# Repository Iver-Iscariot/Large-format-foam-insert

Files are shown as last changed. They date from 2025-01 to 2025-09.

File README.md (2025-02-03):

Making a custom trunk to carry my large format camera, with a fitted foam padding on the inside

CAD file of my camera 

Its a cambo monorail-type large format camera



I have modelled all the components, and laid them out in a desirable, ergonomic layout (Things can be accessed in the order of when you assemble them (this was a issue with the case i bought it in)).
I then drew some simple box-envelopes around them, such that they have some tolerance. These envelope-boxes are also in increments of 5mm height wise, as this is limited by the foam i will be using.

On that, it was hard to find a supplyer of (laser cuttable) foam in norway, but i ended up with this from rufo
https://www.rufo.no/products/50-mm-plastazo3
Its a laminate of 5mm foam layers that can be pulled apart.

Originally, I wanted to fit this in a peli-case with a suitcase-style pullbar and wheels, but there was no way this would fit. Especially since i wanted to store the camera semi-assembled in the case (it typically takes ~20min to take ONE picture with this camera, so every time-save is worth it)
I will therefore simply lasercut a dovetail-plywood box for it, and install some hardware.
To make it suitcase-style, i will use a "sekketralle" from clas ohlson
https://www.clasohlson.com/no/Sammenleggbar-tralle/p/40-8867
I will lasercut some plywood pieces matching the pattern on the bottom, so that it can be slotted onto it (and attached to the handle bar with some sort of straps) I need to use the sekketralle for other stuff, and it is practical to be able to remove the trunk and carry as a backpack with some sort of straps, if you're shooting in rugged terrain

----------------------------------------------------------------------------------------------------------------------------------------------------------------------------------------------------------
EDIT: Making the inside purely out of foam would be VERY expensive. I therefore pivoted to making inside walls, and put padding on them 


I use boxes.py to generate the lasercut-files using this text carefully calculated from my cad file
https://boxes.hackerspace-bamberg.de/TrayLayout?

```
Height: 224 (230 - width)

Uncheck "outside" (da er målene under størrelsen på rommene, som var det jeg målte i cad-filen)
211:31:184:66:71:84
32:115:14:133:49:32

 ,> 211.00mm
 | ,> 31.00mm
 | | ,> 184.00mm
 | | | ,> 66.00mm
 | | | | ,> 71.00mm
 | | | | | ,> 84.00mm
+-+-+-+-+-+-+
|   | | | | |  32.00mm
+   + + + +-+
|   | | | | |  115.00mm
+   +-+-+-+ +
|   | |   | |  14.00mm
+ +-+ +   + +
| | | |   | |  133.00mm
+ +-+-+-+-+ +
|         | |  49.00mm
+   +-+-+-+-+
|   |     | |  32.00mm
+-+-+-+-+-+-+

Sett thickness til 6

Jeg må gjøre litt prøving og feiling for å finne en bra burn correction til mitt materiale før jeg kutter the big one
```
0    burn correction - faller helt fra hverandre, og det er litt synlig hull mellom tabs.
0.01 litt grip, men ikke veldig solid
0.05 Nice grip for en boks i 10cm området, men kan bli litt for tight på en stor boks.
0.1  ALT for tight, går så vidt å få sammen tre sider på en 10cm boks

Kommer til å gå får noe mellom 0.01 og 0.05, kanskje nærmere 0.01, siden boksen er stor (0.02)

Høyden her er gitt ut ifra standardene, som er de høyeste/bredeste tingene som skal med. Boksen er derfor litt høy for resten av objektene. Jeg tenker å løse dette ved å lage små stilaser i boksene, som holder en bit med foam på riktig høyde, og som så holder foam med et cutout til objektet som holder det på plass. Treet som holder skummet må ha tilsvarende cutout, men med litt margin, slik at ikke objektet støter mot det


Lokket er helt likt, bare speilvendt, 69-6 = 63 mm høyt, og med de indre veggene i delen med små-rom fjærnet, slik at én stor skumplate kan holde alt nede

```
Height: 63 (69 - width)

Uncheck "outside" 
84:71:66:184:31:211
32:115:14:133:49:32

 ,> 84.00mm
 | ,> 71.00mm
 | | ,> 66.00mm
 | | | ,> 184.00mm
 | | | | ,> 31.00mm
 | | | | | ,> 211.00mm
+-+-+-+-+-+-+
|       |   |  32.00mm
+       +   +
|       |   |  115.00mm
+       +   +
|       |   |  14.00mm
+       +-+ +
|         | |  133.00mm
+       +-+ +
|       |   |  49.00mm
+       +   +
|       |   |  32.00mm
+-+-+-+-+-+-+

thickness 6
```

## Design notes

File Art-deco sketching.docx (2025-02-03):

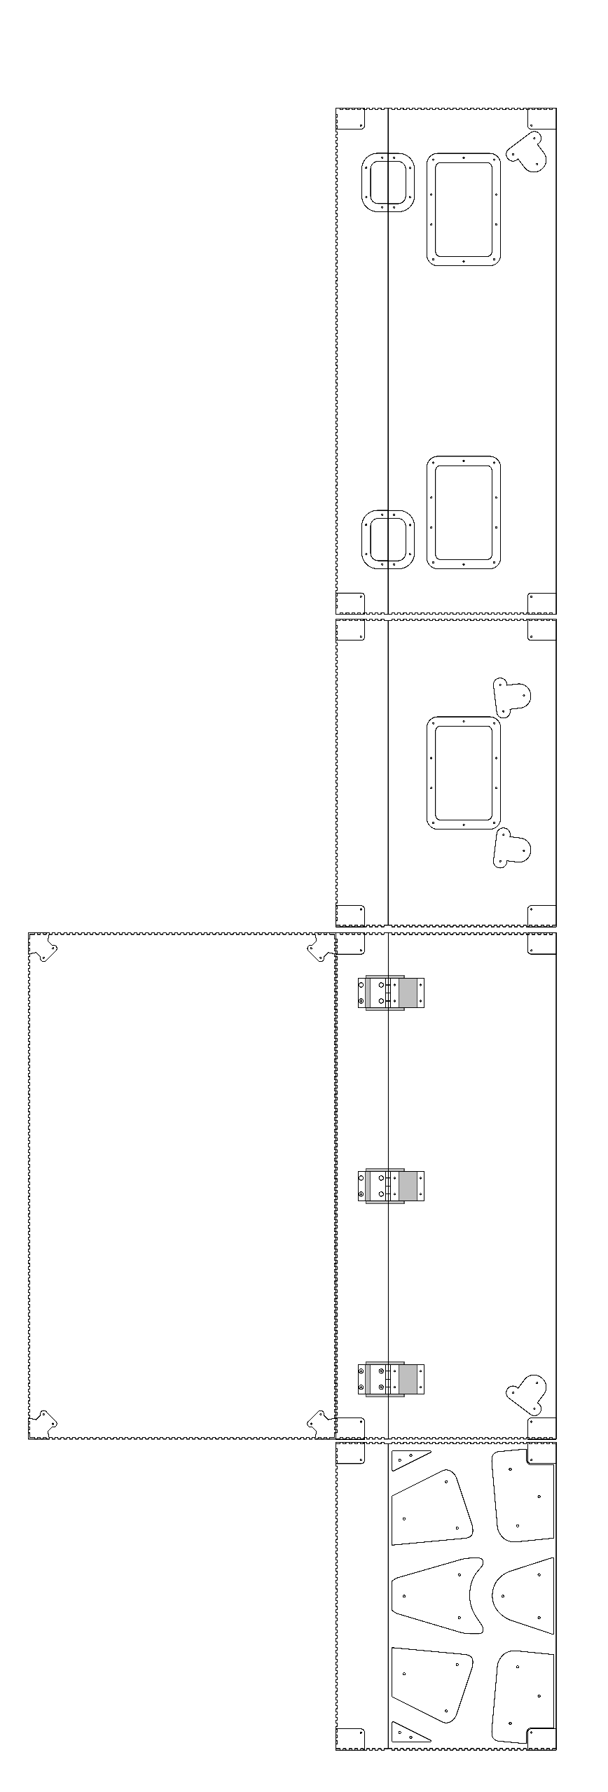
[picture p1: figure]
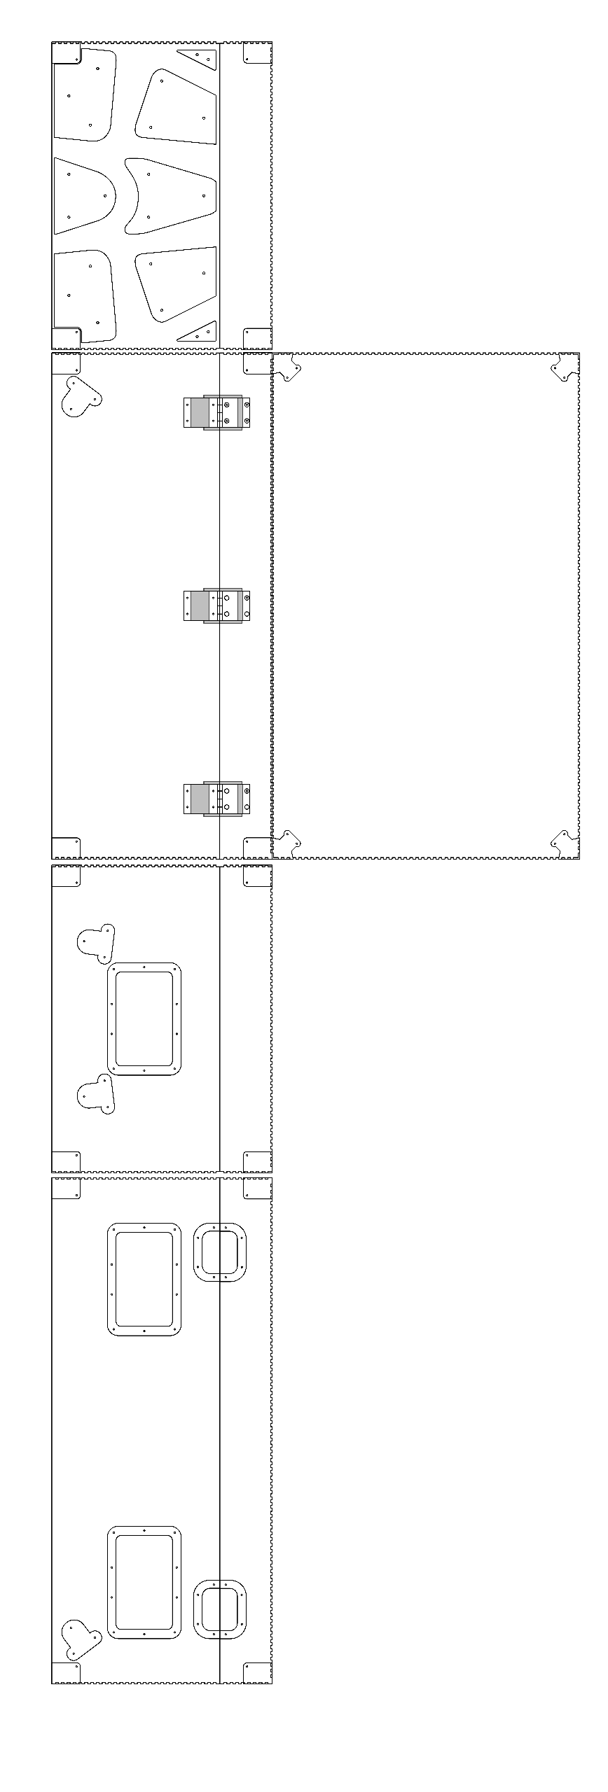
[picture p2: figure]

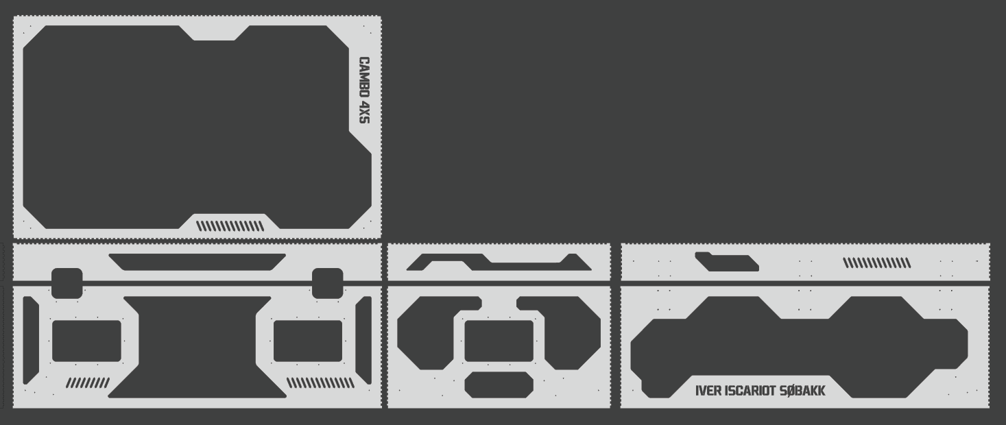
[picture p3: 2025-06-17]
shell preview.png

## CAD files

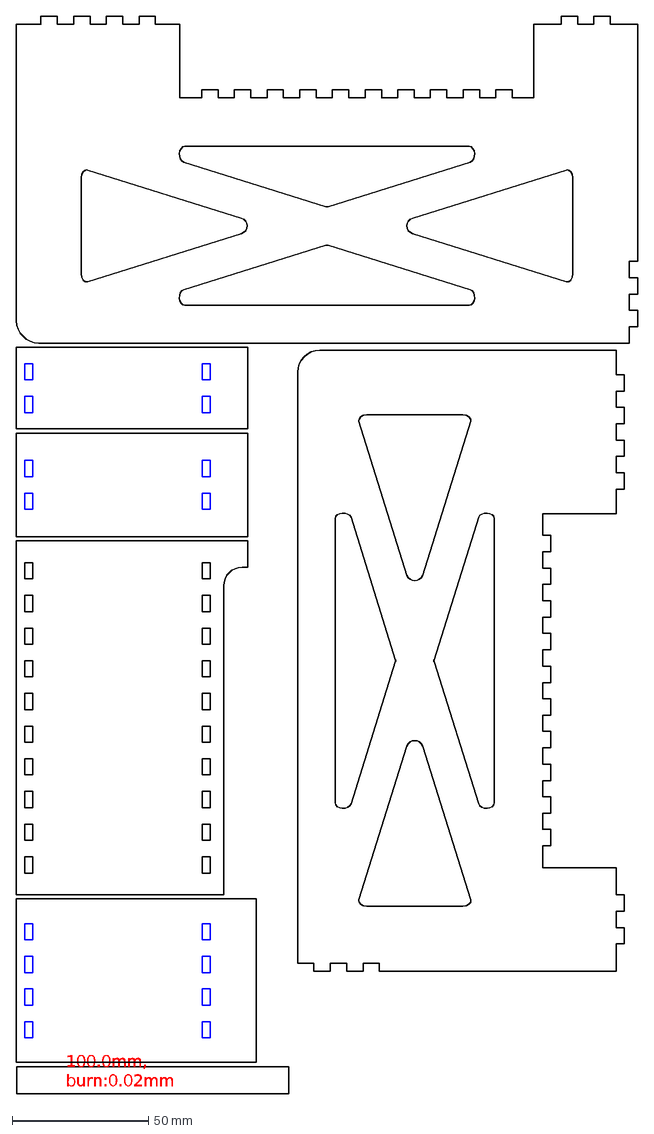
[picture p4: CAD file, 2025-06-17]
inserts/wheels.dxf
100.0mm, burn:0.02mm

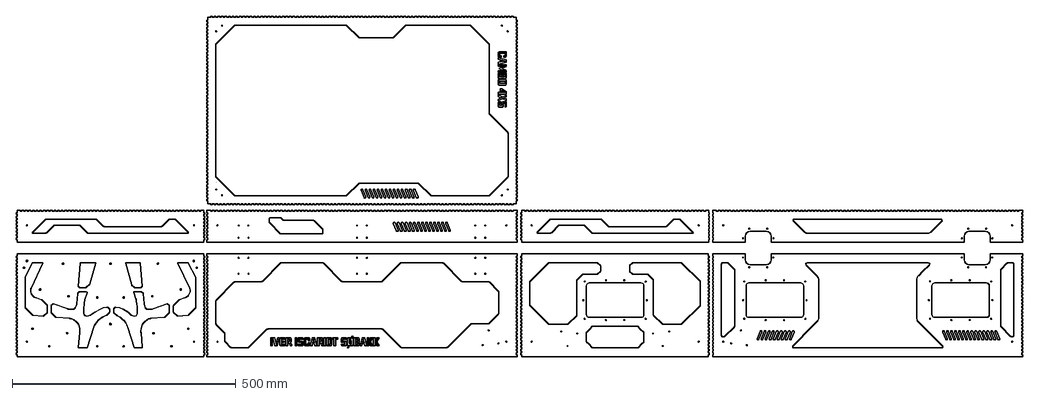
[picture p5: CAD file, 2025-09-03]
outer shell.dxf
2249.2 x 761.0 mm

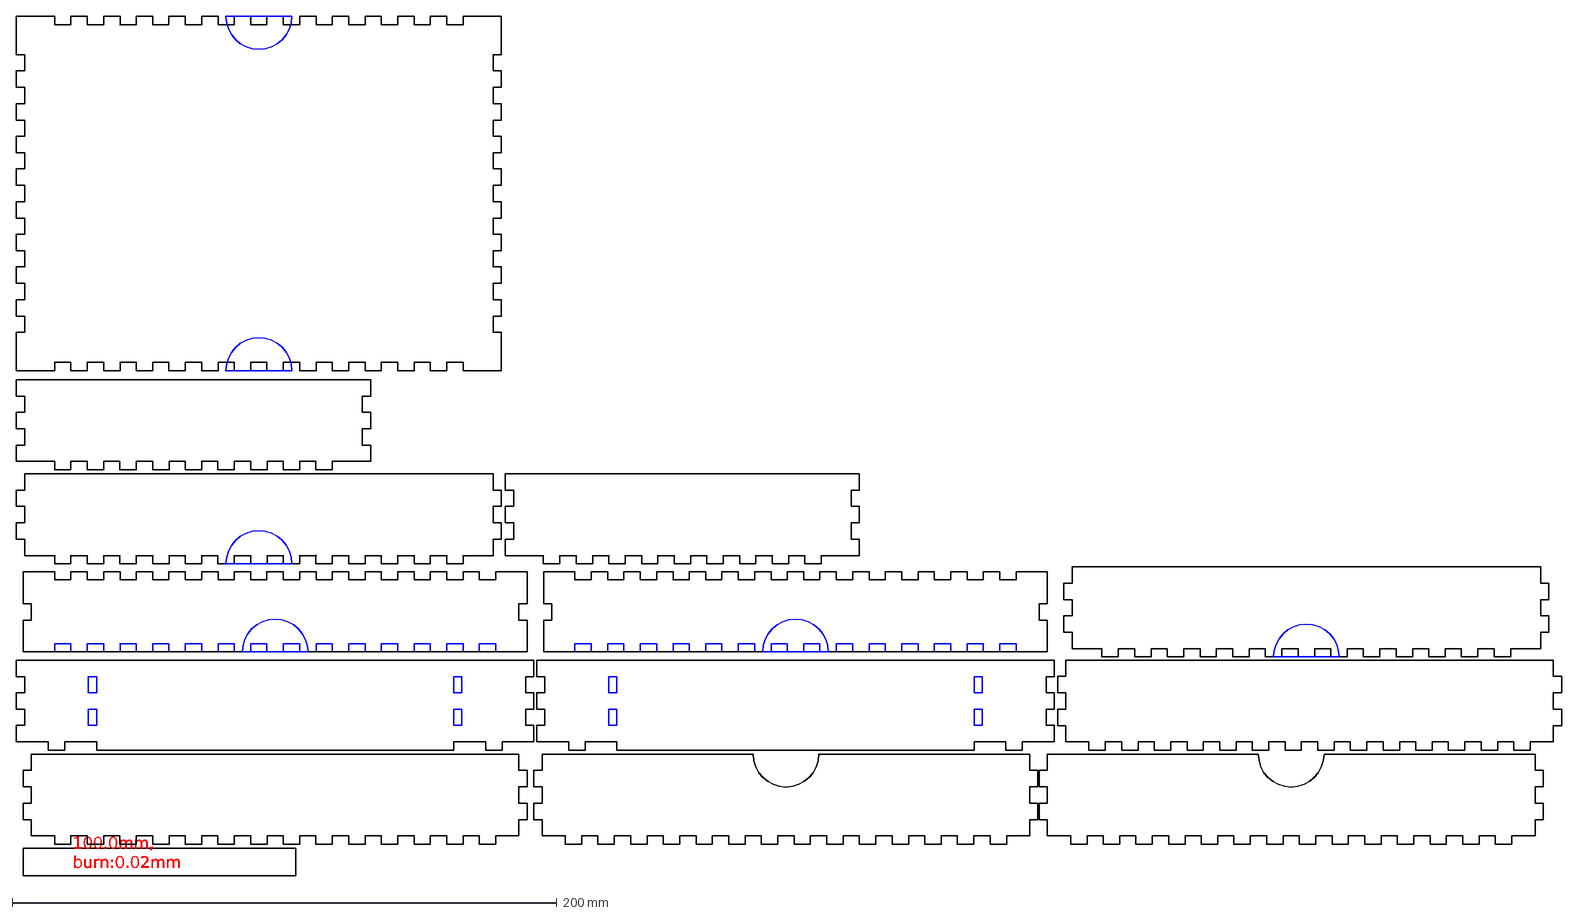
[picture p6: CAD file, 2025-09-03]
roof inserts/lenses.dxf
100.0mm, burn:0.02mm

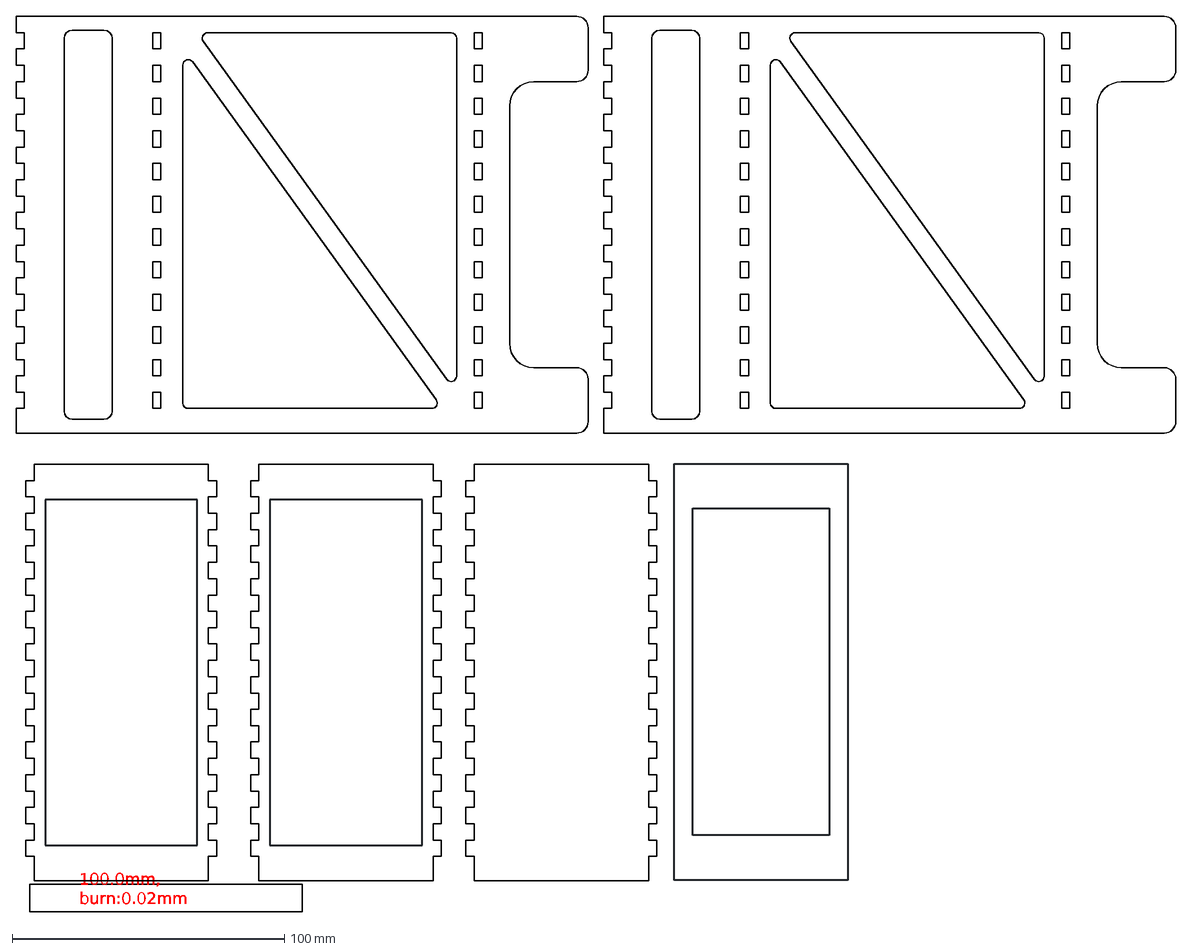
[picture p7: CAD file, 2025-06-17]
inserts/instax.dxf
100.0mm, burn:0.02mm

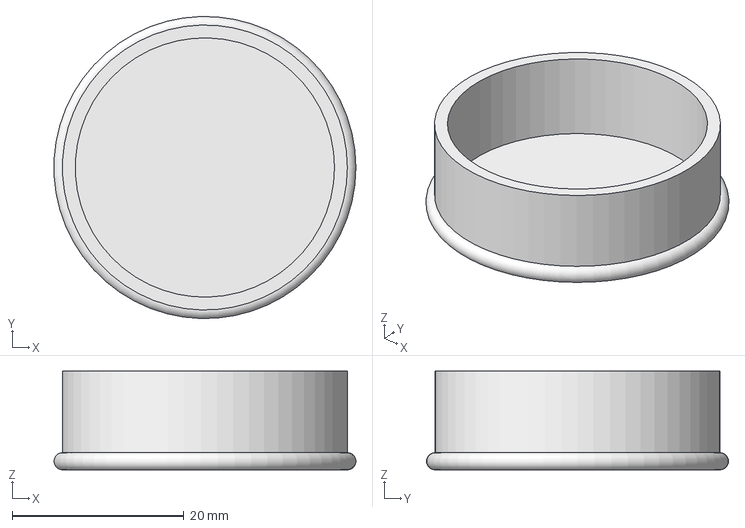
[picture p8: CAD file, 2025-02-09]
Lense cap parameter.FCStd
35.2 x 35.2 x 11.5 mm

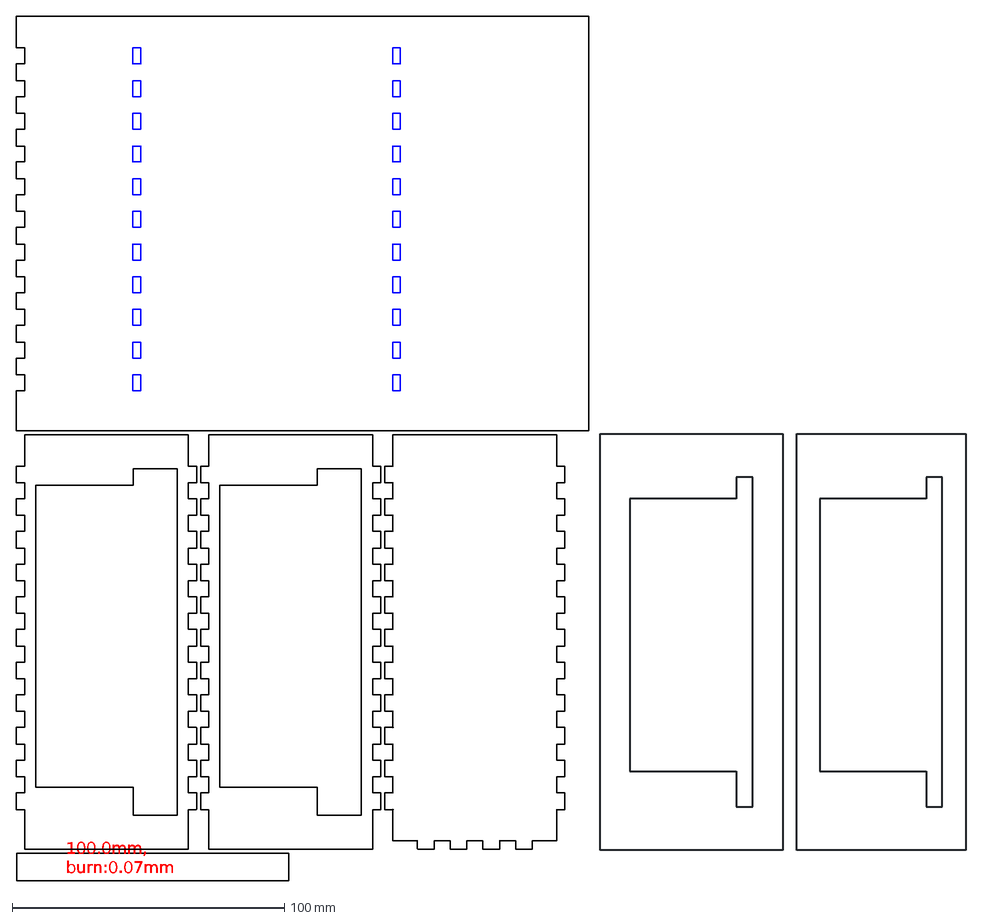
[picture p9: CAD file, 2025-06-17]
inserts/rollback.dxf
100.0mm, burn:0.07mm

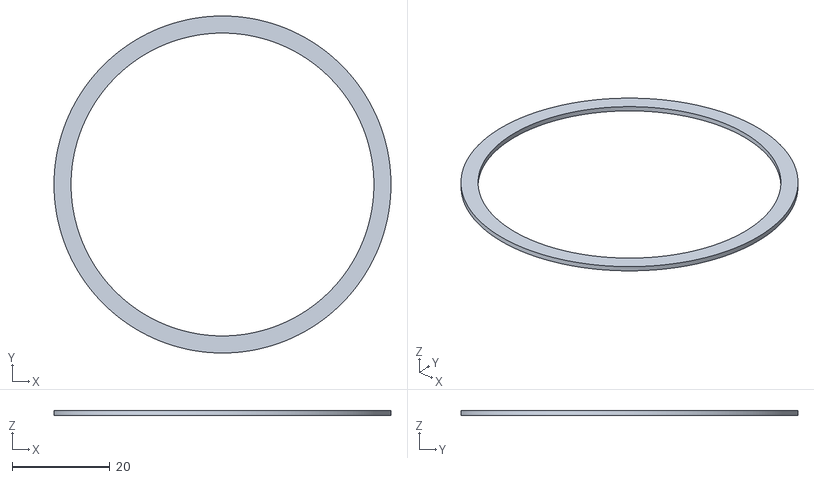
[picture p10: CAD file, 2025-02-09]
ring.stl
69.0 x 69.0 x 1.00

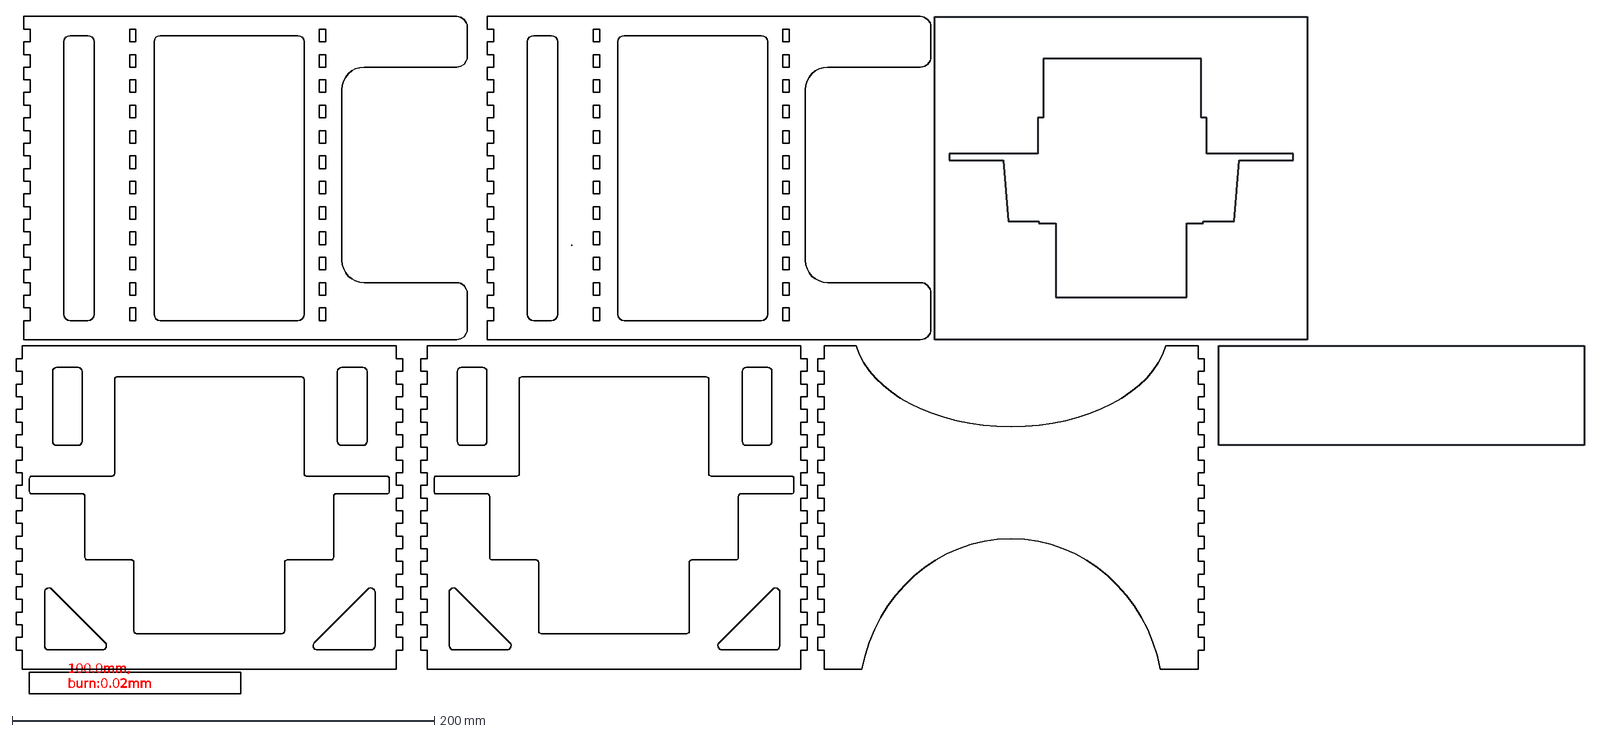
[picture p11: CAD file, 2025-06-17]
inserts/lens.dxf
100.0mm, burn:0.02mm

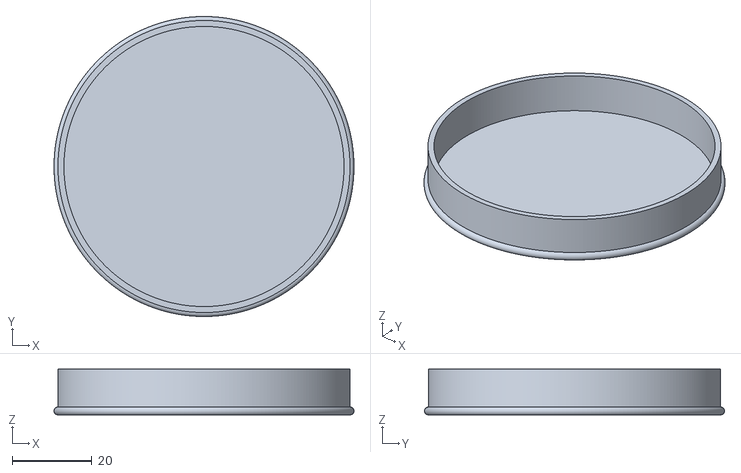
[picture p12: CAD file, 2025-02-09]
Lens cap 70.2mm.stl
75.2 x 75.2 x 11.5

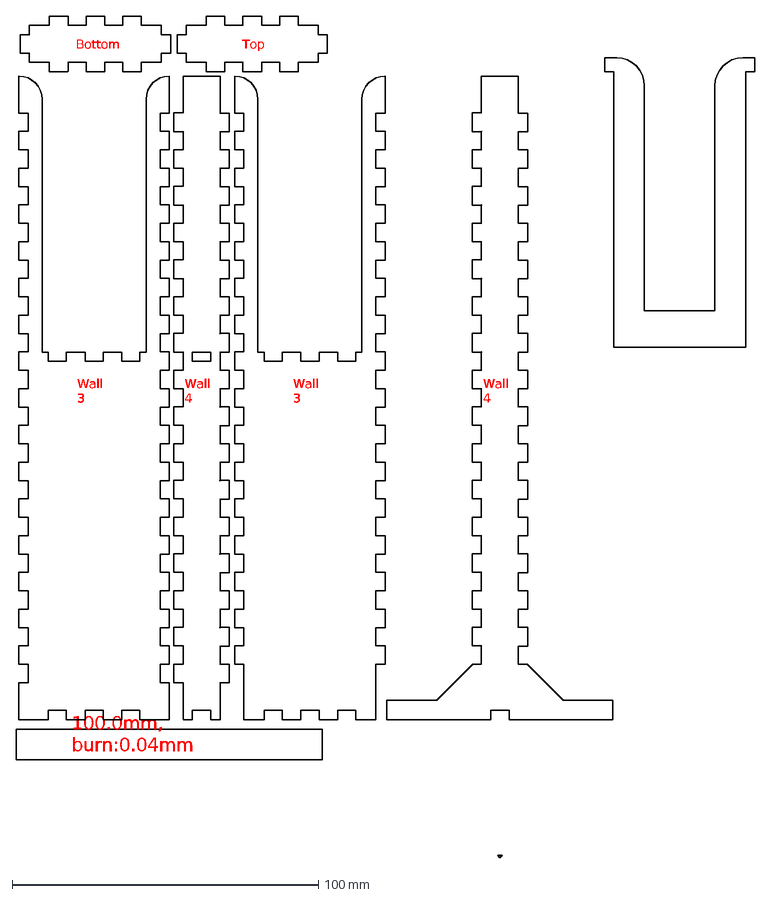
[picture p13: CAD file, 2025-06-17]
inserts/RODHOLDER.dxf
100.0mm, burn:0.04mm
Wall 3
Top
Bottom
Wall 4

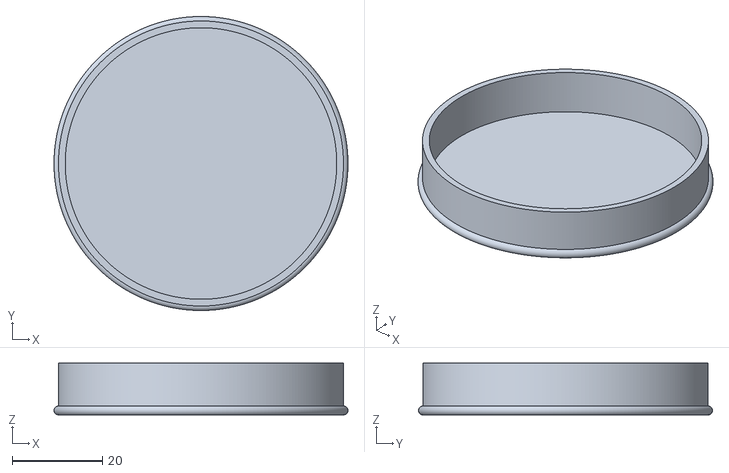
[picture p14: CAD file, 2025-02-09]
Lens cap 60.2mm.stl
65.2 x 65.2 x 11.5

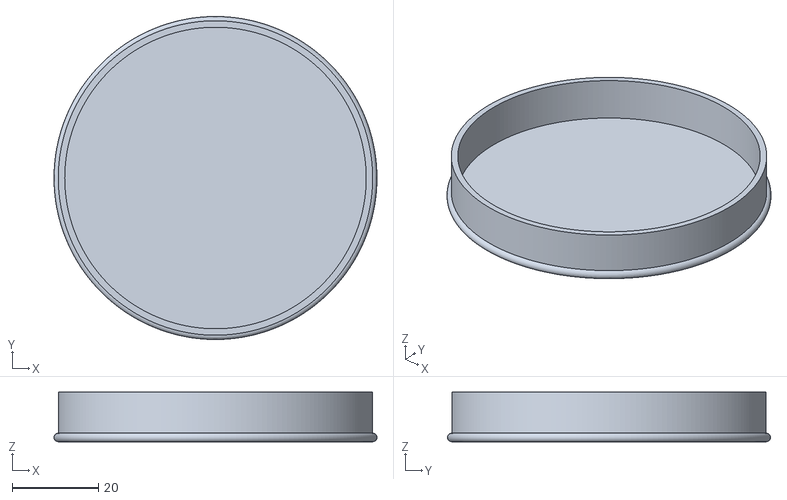
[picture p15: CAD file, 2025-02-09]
Lens cap 70mm.stl
75.0 x 75.0 x 11.5

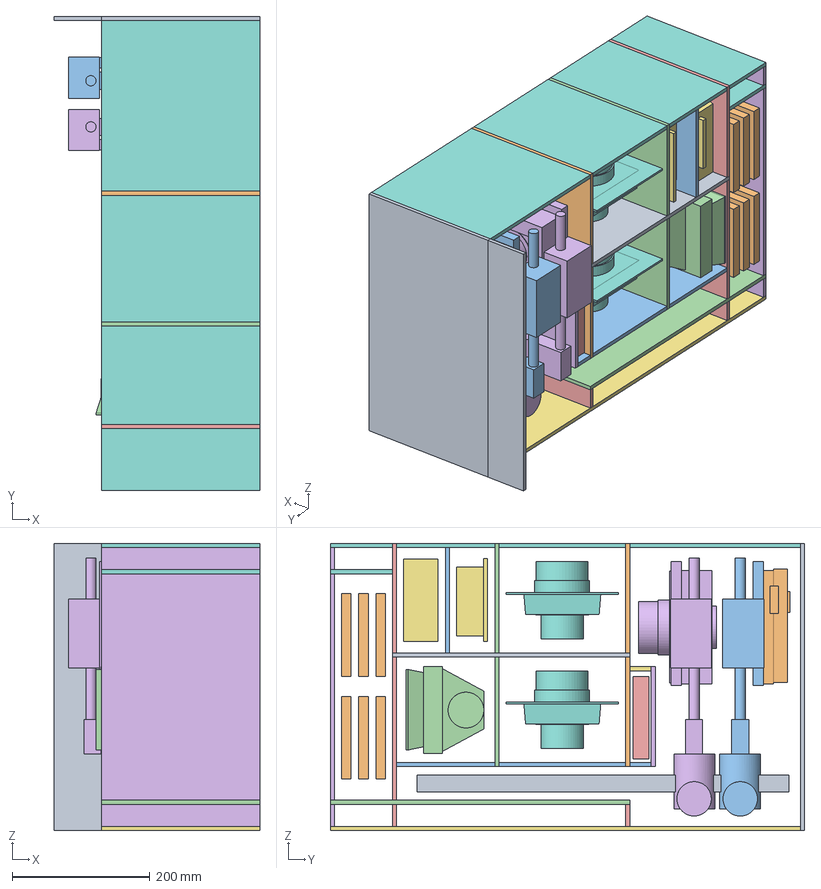
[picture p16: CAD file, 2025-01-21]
foam insert.FCStd
299.0 x 689.0 x 417.0 mm
Rod
ground glass
Standard001
prism
graflok spacer
Front standard with bellow+ lens
3 film golders
lenses

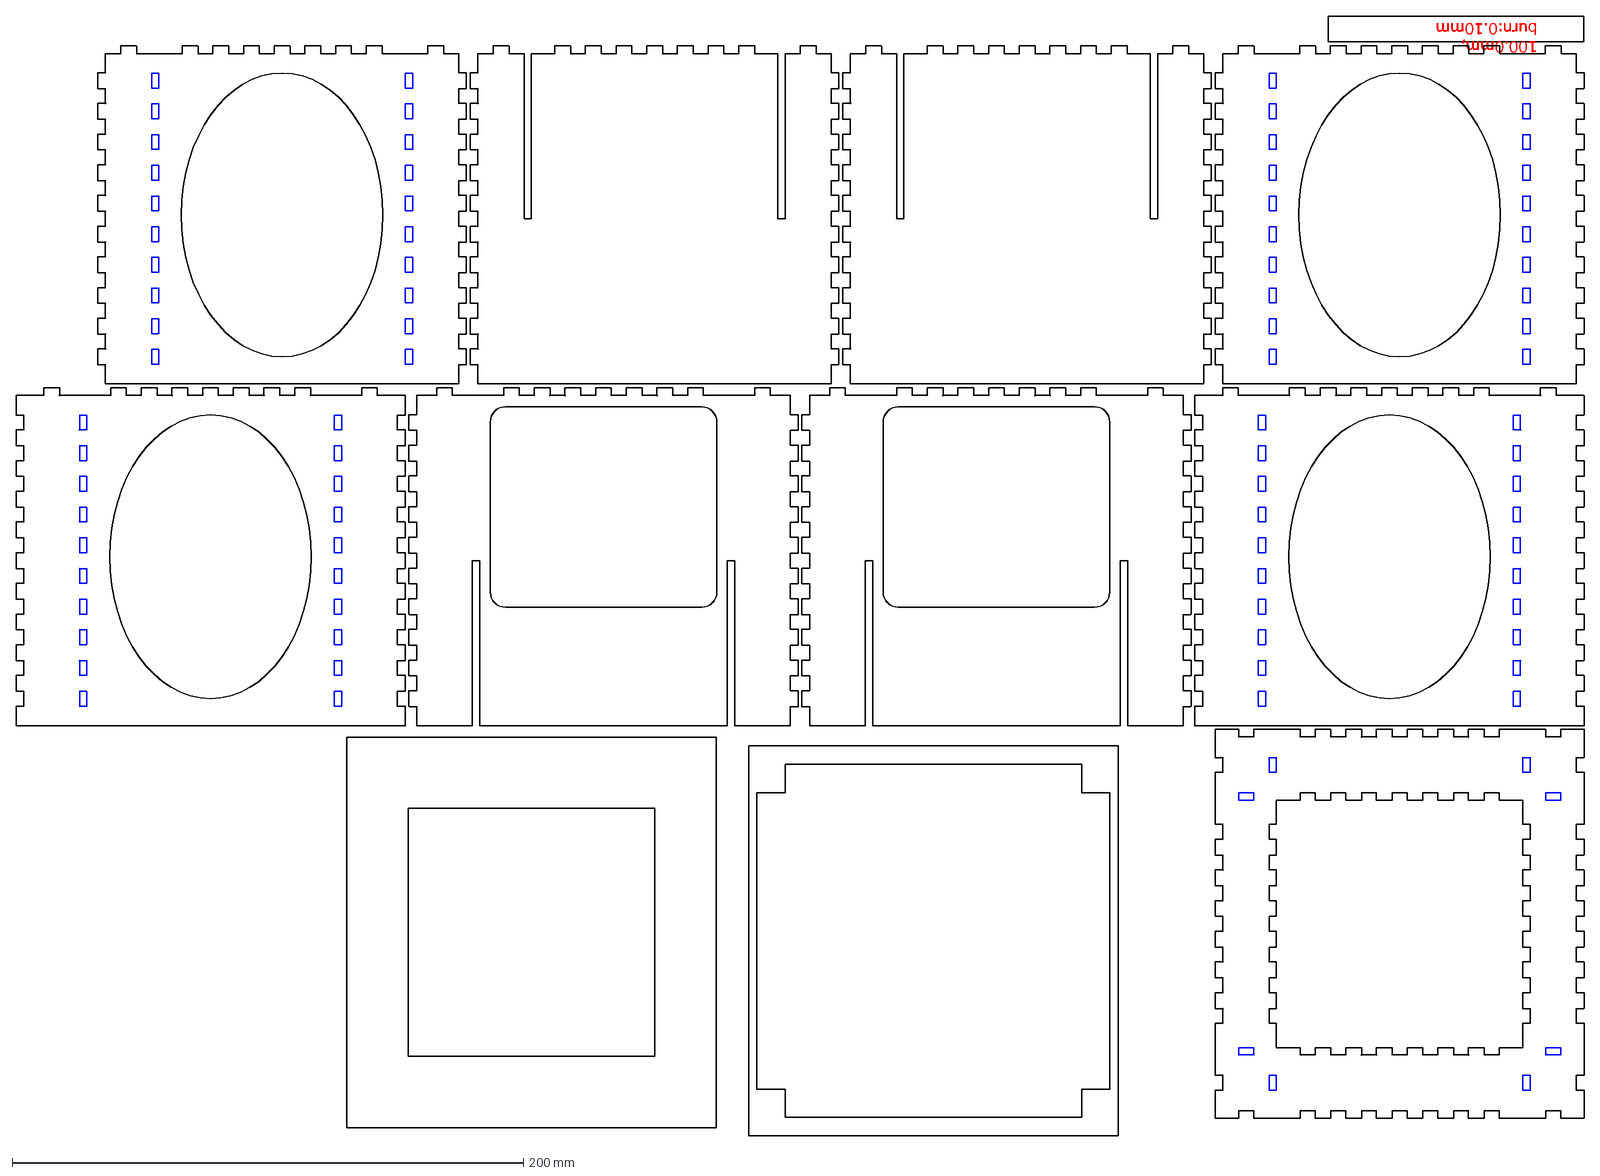
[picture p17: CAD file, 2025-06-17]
inserts/viewfinder.dxf
100.0mm, burn:0.10mm

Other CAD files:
inserts/casettes.dxf

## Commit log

2025-01-03 Lagde fil
    og la inn lomograflok
    [foam insert.FCStd]
2025-01-05 Moddelerte det meste
    Standardene, linsene, belgen og mattglasset. Kommer IKKE til å pase i den kofferten jeg har, så kommer probs til å lage en Custom
    [foam insert.FCStd]
2025-01-07 La til det siste av delene
    [foam insert.FCStd]
2025-01-08 Moddelerte det siste, og begynnte på blokkene som omringer delene
    ie. envelopes som dekker mer en bitene, slik at de har plass med toleranser, og som starter på 5mm incrementer, siden det er det vi er begrenset på av skummplatene
    [foam insert.FCStd]
2025-01-09 Fullført alle envelopes, og cuttet foam blokken
    Mangler å lage finger holes, noen hull for support-stenger (finn diameter) og å hente ut slices for laserkutteren fra dette
    [foam insert.FCStd]
2025-01-10 Lagde finger-holes
    [foam insert.FCStd]
2025-01-20 Må tenke nytt
    Trenger ish 7 lag med foam for å kutte det ut av ren foam (svindyrt) så må tenke nytt. (vegger og gulv av tre inni boksen)
    [foam insert.FCStd]
2025-01-21 Lagde trevegger i stedenfor foam
    Og la til den nye rullfilm-holderen
    [foam insert.FCStd]
2025-01-22 Begynnt på Vektorfiler for laserkutter
2025-02-09 3D print files
    [Lens cap 60.2mm.stl, Lens cap 70.2mm.stl, Lens cap 70mm.stl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]
2025-02-11 Ungroupet ting, slik at laserkuttern klarer å tyde det
2025-02-18 Update case bunn.ai
2025-06-17 Lagde inserts for å holde de individuelle delene
    [RODHOLDER.dxf, casettes.dxf, instax.dxf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]
2025-09-03 final ver mdf outer shell
    [outer shell.dxf]
2025-09-03 added lid padding file
    [lenses.dxf]
